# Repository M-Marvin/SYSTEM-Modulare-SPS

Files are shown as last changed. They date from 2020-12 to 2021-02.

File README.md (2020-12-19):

# SYSTEM-Modulare-SPS
Eine Modulares SPS System aus einem Raspberry Pi und ATmega328 Microcontrolern

Das Projekt ist noch nicht fertig, aber auf einem Steckbrett hat es schon funktioniert!

WISCHTIG: Datei wird auf der GitHub Webseite verbuggt angezeigt, besser runterladen und mit standart Texteditor öffnen!

-----------------------------------------------------------------------------------------------------

Die Modulare SPS besteht aus einem Raspberry Pi. der über ein Adaptermodul und
einem Flachbandkabel mit den einzelnen Modulen verbunden wird.

Die Moduel bestehen aus auf Hut-Schienen anbringbaren 3D-Gedruckten Gehäusen mit
entsprechenden Schaltungen darin.

Bisherige Module:
  - keine

In Entwiklung:
  - DO_16_R230  16 x Digitalausgang mit 230V Relay-Wechlerkontakten

Geplante Module:
  - DI_16_D24   16 x Digitaleingang 24V direkt gekoppelt (keine Relays dazwischen)
  - AI_1_D0-24  1 x Analogeingang 0V-24V direkt gekoppelt
  - AO_1_D0-24 1 x Analogausgang 0V-24V direkt gekoppelt (benötigt 24V Spannungsversorgung)

-----------------------------------------------------------------------------------------------------

Kurzbezeichnungs-Legende:

Beispiel: DO - 16 - R230

D = Digital (1 oder 0 / Ein oder Aus)
O = Output (Ausgang)

16 = Schnittstelle 16 mal vorhanden

R = Relay/Galvanisch getrennt
230 = Maximale Spannung 230V

Zusammensetzung: [Art der Schnittstelle] [Eingang/Ausgang*] _ [Anzahl der Schnittstellen] _ [Kopplungsart] [Maximal-Spannung/Spannungsbereich]
* (oder weggelassen wenn nicht klar definierbar, z.B: bei Netzwerk)

[Art der Schnittstelle]
- D Digital
- A Analog
- B Bus-System (zu Zeit noch nicht verwended, z.B. Netzwerk, D-Sub, MPI, ISP, USB, usw.)

[Eingang/Ausgang]
- I Eingang
- O Ausgang

[Kopplungsart]
- R Relay/Galvanisch getrennt
- D Direkt gekoppelt (GND der Leiterplatte/SPS und GND der Externen Anschlüsse sind identisch)

-----------------------------------------------------------------------------------------------------

Das projekt besteht aus:
- Raspberry Pi SPS Hauptprogramm (Dort wird das Programm der Steuerung und die Einstellung der Module reingeladen)
- ATmega Modul-Programme (Programme der jeweiligen Module)
- Schaltpläne/Leiterplatten entwürfe
- 3D-Druck Modelle für Gehäuse/Halterungen

Das Raspberry Pi Programm läuft mit der Bibliothek pi4j auf jedem kompatiblen Raspebrry Pi.
Die Datei wird einfach auf das Pi kopiert und über einen der folgenden Befehle gestartet:
    sudo java -jar *Pfad der Jar*               um das SPS Programm zu starten
    sudo java -jar *Pfad der Jar* -configMode   um den System-Konfigurator zu starten und die Adressen der Module fest zu legen

Die ATmega Programme werden als .hex (Textdatei mit Hexadezimal-Codes) compiliert und per SPI in den Controler geladen.

-----------------------------------------------------------------------------------------------------

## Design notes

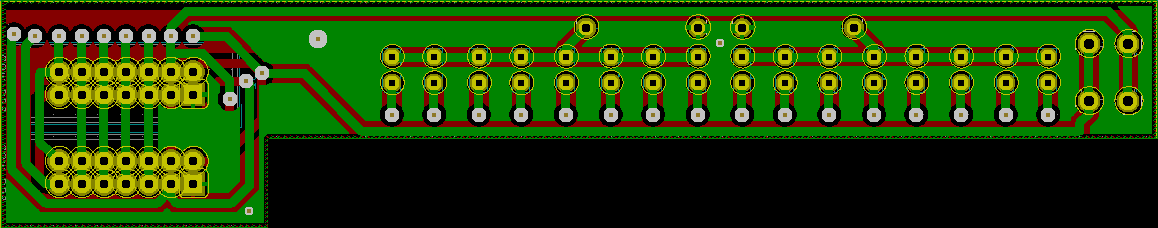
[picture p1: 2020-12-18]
Projekt-3D-Modelle/DO_16_R230/DO_16_R230 Front.PNG

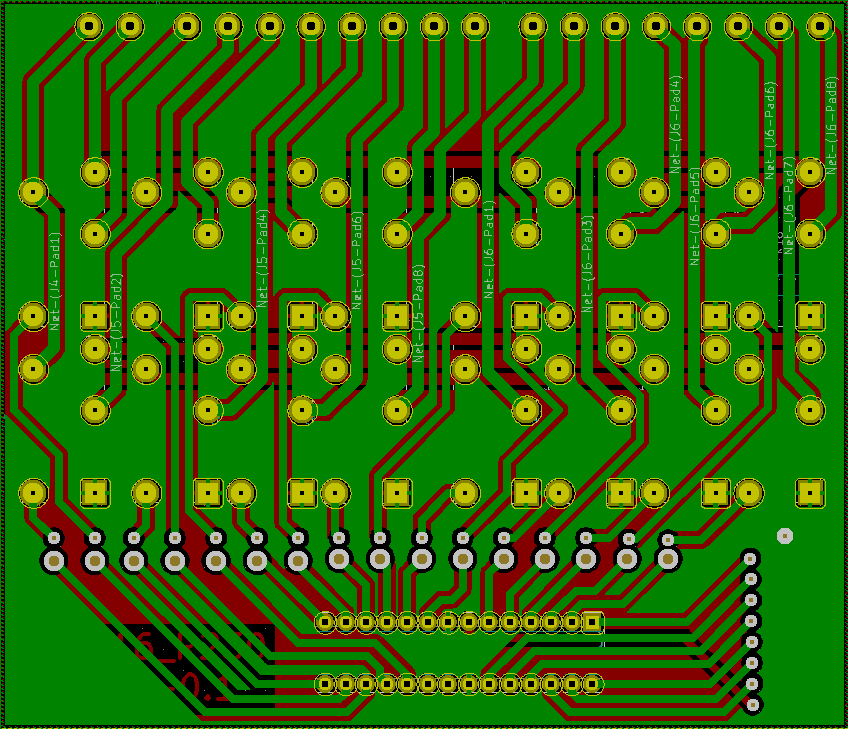
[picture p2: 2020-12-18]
Projekt-3D-Modelle/DO_16_R230/DO_16_R230 Main.PNG

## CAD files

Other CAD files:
Projekt-3D-Modelle/DO_16_R230/Gesamt.skp

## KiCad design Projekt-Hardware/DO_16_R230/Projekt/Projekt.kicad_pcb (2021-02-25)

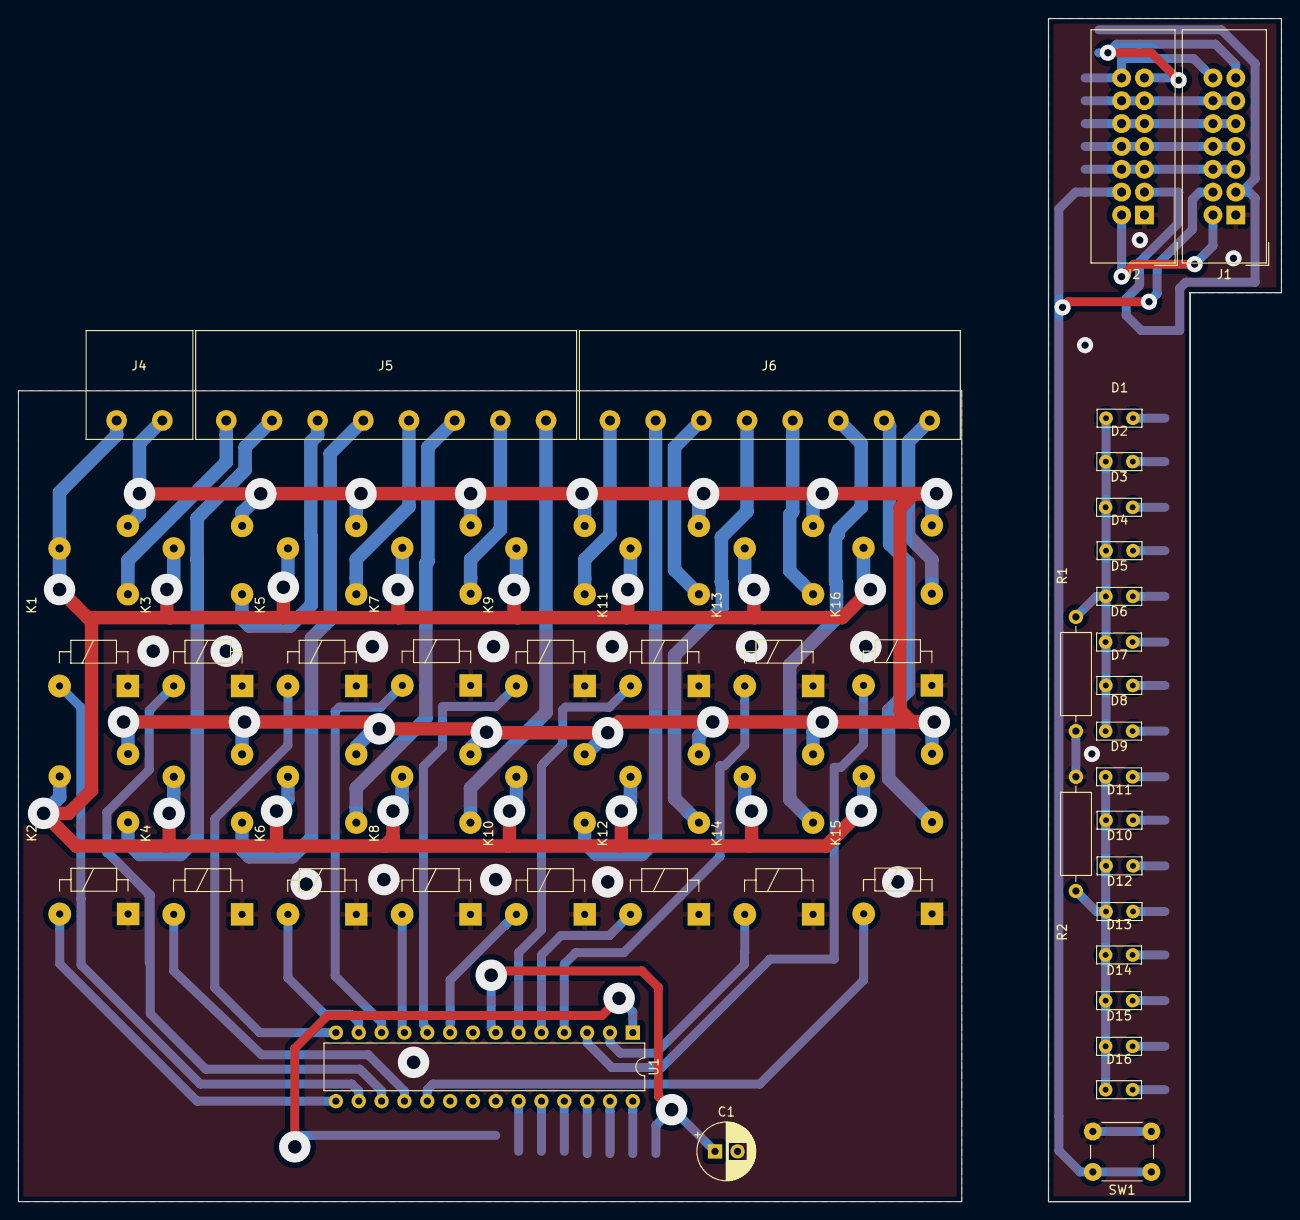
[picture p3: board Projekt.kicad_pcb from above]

Board: 2 copper layers, 140.5 x 131.6 mm, 42 parts (0 on the bottom side), 46 nets.

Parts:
C1: 10uF; CP_Radial_D6.3mm_P2.50mm
D1, D2, D3, D4, D5, D6, D7, D8, D9, D10, D11, D12, D13, D14, D15, D16: LED; LED_5x2mm
J1, J2: COM_Bus; IDC-Header_2x07_P2.54mm_Vertical
J4: Conn_01x02; RND_Steckklemme_2
J5, J6: Conn_01x08; RND_Steckklemme_8
K1, K2, K3, K4, K5, K6, K7, K8, K9, K10, K11, K12, K13, K14, K15, K16: DIPxx-1Cxx-51x; Relay_1-Form-C-20,6x10,2mm
R1, R2: 220R; R_Axial_DIN0309_L9.0mm_D3.2mm_P12.70mm_Horizontal
SW1: RESET; SW_PUSH_6mm_H8mm
U1: ATmega328P-PU; DIP-28_W7.62mm

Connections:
/+5V: C1.1, J1.2, J2.2, U1.7
/-5V: J1.3, J2.3
/CLOCK: J1.13, J2.13, U1.27
/COM_IN_1: J1.5, J1.6, J2.5, J2.6, U1.25
/COM_IN_2: J1.7, J1.8, J2.7, J2.8, U1.26
/COM_OUT_1: J1.9, J1.10, J2.9, J2.10, U1.23
/COM_OUT_2: J1.11, J1.12, J2.11, J2.12, U1.24
/ENABLE: J1.14, J2.14, U1.28
/GND: C1.2, J1.1, J2.1, K1.6, K2.6, K3.6, K4.6, K5.6, K6.6, K7.6, K8.6, K9.6, K10.6, K11.6, K12.6, K13.6, K14.6, K15.6, K16.6, R1.2, R2.2, SW1.0,82, SW1.2, U1.8, U1.22
/RESET: J1.4, J2.4, SW1.0,81, SW1.1, U1.1
unnamed: D1.1, D2.1, D3.1, D4.1, D5.1, D6.1, D7.1, D8.1, R1.1
unnamed: D1.2, K1.2, U1.16
unnamed: D2.2, K2.2, U1.15
unnamed: D3.2, K3.2, U1.17
unnamed: D4.2, K4.2, U1.18
unnamed: D5.2, K5.2, U1.14
unnamed: D6.2, K6.2, U1.13
unnamed: D7.2, K7.2, U1.12
unnamed: D8.2, K8.2, U1.11
unnamed: D9.2, K9.2, U1.10
unnamed: D9.1, D10.1, D11.1, D12.1, D13.1, D14.1, D15.1, D16.1, R2.1
unnamed: D10.2, K10.2, U1.9
unnamed: D11.2, K11.2, U1.6
unnamed: D12.2, K12.2, U1.5
unnamed: D13.2, K13.2, U1.4
unnamed: D14.2, K14.2, U1.2
unnamed: D15.2, K15.2, U1.19
unnamed: D16.2, K16.2, U1.3
unnamed: J4.1, K1.1, K2.1, K3.1, K4.1, K5.1, K6.1, K7.1, K8.1, K9.1, K10.1, K11.1, K12.1, K13.1, K14.1, K15.1, K16.1
unnamed: J4.2, K1.14, K2.14, K3.14, K4.14, K5.14, K6.14, K7.14, K8.14, K9.14, K10.14, K11.14, K12.14, K13.14, K14.14, K15.14, K16.14
unnamed: J5.1, K1.7
unnamed: J5.2, K2.7
unnamed: J5.3, K3.7
unnamed: J5.4, K4.7
unnamed: J5.5, K5.7
unnamed: J5.6, K6.7
unnamed: J5.7, K7.7
unnamed: J5.8, K8.7
unnamed: J6.1, K9.7
unnamed: J6.2, K10.7
unnamed: J6.3, K11.7
unnamed: J6.4, K12.7
unnamed: J6.5, K13.7
unnamed: J6.6, K14.7
unnamed: J6.7, K15.7
unnamed: J6.8, K16.7

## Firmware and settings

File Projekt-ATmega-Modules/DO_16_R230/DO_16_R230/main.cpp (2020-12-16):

/*
 * comInterface.c
 * Module main file
 *
 * Created: 11/16/2020 7:30:22 PM
 *  Author: Marvin
 * 
 * PIN CONFIG
 * Relays
 * PORTD 0-7 + PORTB 0-7
 * COM Serial OUT
 * PORTC 0-1
 * COM Serial IN
 * PORTC 2-3
 * Clock
 * PINC 4
 */ 

#include "system.cpp"

int main(void)
{
	
	System sys;
	sys.start();
	
}

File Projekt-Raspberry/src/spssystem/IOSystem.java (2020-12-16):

package spssystem;

import com.pi4j.io.gpio.GpioController;
import com.pi4j.io.gpio.GpioFactory;
import com.pi4j.io.gpio.GpioPinDigitalInput;
import com.pi4j.io.gpio.GpioPinDigitalOutput;
import com.pi4j.io.gpio.PinPullResistance;
import com.pi4j.io.gpio.PinState;
import com.pi4j.io.gpio.RaspiPin;

public class IOSystem {
	
	protected boolean clockPulseState;
	protected byte[] inputList;
	protected byte[] inputBytes;
	protected byte[] outputList;
	protected byte[] outputBytes;
	
	protected GpioController gpio;
	protected GpioPinDigitalOutput outputEnable;
	protected GpioPinDigitalOutput outputSync;
	protected GpioPinDigitalOutput outputCom1;
	protected GpioPinDigitalOutput outputCom2;
	protected GpioPinDigitalInput inputCom1;
	protected GpioPinDigitalInput inputCom2;
	
	public IOSystem() {
		this.inputBytes = new byte[0];
		this.inputList = new byte[0];
		this.outputBytes = new byte[0];
		this.outputList = new byte[0];
		
		try {
			gpio = GpioFactory.getInstance();
			outputEnable = gpio.provisionDigitalOutputPin(RaspiPin.GPIO_01, "enable", PinState.LOW);
			outputEnable.setShutdownOptions(true, PinState.LOW, PinPullResistance.OFF);
			outputSync = gpio.provisionDigitalOutputPin(RaspiPin.GPIO_08, "sync", PinState.LOW);
			outputSync.setShutdownOptions(true, PinState.LOW, PinPullResistance.OFF);
			outputCom1 = gpio.provisionDigitalOutputPin(RaspiPin.GPIO_09, "oCom1", PinState.LOW);
			outputCom1.setShutdownOptions(true, PinState.LOW, PinPullResistance.OFF);
			outputCom2 = gpio.provisionDigitalOutputPin(RaspiPin.GPIO_07, "oCom2", PinState.LOW);
			outputCom2.setShutdownOptions(true, PinState.LOW, PinPullResistance.OFF);
			inputCom1 = gpio.provisionDigitalInputPin(RaspiPin.GPIO_00, "iCom1");
			inputCom1.setPullResistance(PinPullResistance.PULL_DOWN);
			inputCom2 = gpio.provisionDigitalInputPin(RaspiPin.GPIO_02, "iCom2");
			inputCom2.setPullResistance(PinPullResistance.PULL_DOWN);
		} catch (UnsatisfiedLinkError e) {
			System.err.println("SPSSystem cant connect to wiringPi netive Lib!");
			System.err.println(e.getMessage());
			System.exit(-1);
		}
		
	}
	
	public void shutdown() {
		this.gpio.shutdown();
	}
	
	public void registerInputRange(byte adress, byte byteWidth, int requestTime) {
		
		inputList = ByteUtility.mergeData(inputList, new byte[] {adress, byteWidth}, ByteUtility.intToBytes(requestTime));
		inputBytes = ByteUtility.mergeData(this.inputBytes, new byte[byteWidth]);
		
	}
	
	public void registerOutputRange(byte adress, byte byteWidth, int updateTime) {
		
		outputList = ByteUtility.mergeData(outputList, new byte[] {adress, byteWidth}, ByteUtility.intToBytes(updateTime));
		outputBytes = ByteUtility.mergeData(this.outputBytes, new byte[byteWidth]);
		
	}
	
	public void setOutputByte(byte adr, int targetByte, byte ioByte) {

		int ioByteOffset = 0;
		for (int modCnt = 0; modCnt < outputList.length; modCnt += 6) {
			
			byte adress = outputList[modCnt + 0];
			byte byteWidth = outputList[modCnt + 1];
			
			if (adress == adr && targetByte < byteWidth) {
				
				this.outputBytes[ioByteOffset + targetByte] = ioByte;
				
			}
			
			ioByteOffset += byteWidth;
			
		}
				
	}
	
	public byte getOutputByte(byte adr, int targetByte) {
		
		int ioByteOffset = 0;
		for (int modCnt = 0; modCnt < outputList.length; modCnt += 6) {
			
			byte adress = outputList[modCnt + 0];
			byte byteWidth = outputList[modCnt + 1];
			
			if (adress == adr && targetByte < byteWidth) {
				
				return this.outputBytes[ioByteOffset + targetByte];
				
			}
			
			ioByteOffset += byteWidth;
			
		}
		
		return 0;
		
	}

	public void setInputByte(byte adr, int targetByte, byte ioByte) {

		int ioByteOffset = 0;
		for (int modCnt = 0; modCnt < inputList.length; modCnt += 6) {
			
			byte adress = inputList[modCnt + 0];
			byte byteWidth = inputList[modCnt + 1];
			
			if (adress == adr && targetByte < byteWidth) {
				
				this.inputBytes[ioByteOffset + targetByte] = ioByte;
				
			}
			
			ioByteOffset += byteWidth;
			
		}
				
	}
	
	public byte getInputByte(byte adr, int targetByte) {
		
		int ioByteOffset = 0;
		for (int modCnt = 0; modCnt < inputList.length; modCnt += 6) {
			
			byte adress = inputList[modCnt + 0];
			byte byteWidth = inputList[modCnt + 1];
			
			if (adress == adr && targetByte < byteWidth) {
				
				return this.inputBytes[ioByteOffset + targetByte];
				
			}
			
			ioByteOffset += byteWidth;
			
		}
		
		return 0;
		
	}
	
	protected void waitTick() {
		try {
			Thread.sleep(0, 100);
		} catch (InterruptedException e) {
			// TODO Auto-generated catch block
			e.printStackTrace();
		}
	}
	
	public void readInputs() {

		setLow();
		outputEnable.high();
		
		long sysClock = SPSSystem.getSystem().getSystemClock();
		int ioByteOffset = 0;
		
		for (int modCnt = 0; modCnt < inputList.length; modCnt += 6) {
			
			byte adress = inputList[modCnt + 0];
			byte byteWidth = inputList[modCnt + 1];
			int requestTime = ByteUtility.bytesToInt(ByteUtility.copyArr(inputList, modCnt + 2, modCnt + 5));
			
			if (sysClock % requestTime == 0) {
				
				waitTick();
				
				byte[] data = readModul(adress);
				
				if (data.length >= byteWidth) {
					
					byte[] data2 = ByteUtility.copyArr(data, 0, byteWidth);
					ByteUtility.replaceBytes(this.inputBytes, ioByteOffset, data2);
					
				}
				
			}
			
			ioByteOffset += byteWidth;
			
		}

		setLow();
		outputEnable.low();
		
	}
	
	public void writeOutputs() {
		
		setLow();
		outputEnable.high();
		
		long sysClock = SPSSystem.getSystem().getSystemClock();
		int ioByteOffset = 0;
		
		for (int modCnt = 0; modCnt < outputList.length; modCnt += 6) {
			
			byte adress = outputList[modCnt + 0];
			byte byteWidth = outputList[modCnt + 1];
			int requestTime = ByteUtility.bytesToInt(ByteUtility.copyArr(outputList, modCnt + 2, modCnt + 5));
			
			if (sysClock % requestTime == 0) {

				waitTick();
				
				byte[] data = ByteUtility.copyArr(this.outputBytes, ioByteOffset, ioByteOffset + byteWidth - 1);
				writeModul(adress, data);
				
			}
			
			ioByteOffset += byteWidth;
			
		}

		setLow();
		outputEnable.low();
		
	}
	
	public byte[] writeAdressConfig(byte adress, byte masterAdress) {
		
		setLow();
		outputEnable.high();
		
		byte[] data = new byte[] {adress};
		writeModul(masterAdress, data);
		byte[] response = readBytes();
		
		setLow();
		outputEnable.low();
		
		return response;
		
	}
	
	protected void setLow() {
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

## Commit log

2020-12-07 Hochladen des Aktuellen Projekt-Stands
    Raspberry:
    - Java-Software zum betrieb der Steuerung
    - Netzwerk fähig
    - GPIO/Module (Ein/Ausgänge) noch nicht implementiert
    ATmega:
    - Software für DO_16_R230 (16x230V Relay-Ausgänge) Modul
    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
    [Projekt.kicad_pcb, Projekt.sch]
2020-12-16 Modul-Kommunikation fertig
    Protokoll zur Kommunikation zwischen
    ATmega und Raspberry Pi fertig gestellt.
    (Änderungen kommen eventuell noch)
2020-12-16 EEPROM Speicher für Modul Adresse
    Die Adresse des Moduls DO_16_R230 wird
    jetzt bei Ein/Aus schalten im EEPROM des ATmega328 gespeichert.
2020-12-17 Erster (meschanischer) Entwurf für DO_16_R230 Modul
    Erster Entwurf für meschanische Bauteile des
    DO_16_R230 Moduls:
    - Entwurf für Leiterplatten
    Fehlende Entwürfe:
    - Gehäuse
    - Halterungen
    [Projekt.kicad_pcb, Projekt.sch]
2020-12-17 BugFix PortState Abfrage DO_16_R230 Modul
    PORT Angaben bei der Abfrage der Ausgangszustände korigiert.
    Unnötiges "Testprojekt" gelöcht (GccApplication1).
    [system.cpp]
2020-12-18 Gehäuse für DO_16_R230 begonnen
    Angefangen Gehäuse für DO_16_R230
    angefangen zu entwerfen.
    [Gesamt.skp, Projekt.kicad_pcb, Projekt.sch]
2020-12-19 BugFix bei 3D Modells
    Fehler in den 3D Modellen behoben.
    Sie können jetzt gedruckt werden.
    [Gesamt.skp]
2020-12-19 Korrektur im Schaltplan
    RESET Taster auf von +5V auf GND verschoben.
    [Projekt.kicad_pcb, Projekt.sch]
2020-12-26 Anpassungen Gehäuse + CNC Experimente
    Anpassungen des Gehäuses an die Leiteplatte
    Angefangen mit Tests für das herstellen der Leiterplatte mit einer CNC Fräse
    [Gesamt.skp, Projekt.kicad_pcb, Projekt.sch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]
2021-02-25 Hardware CNC Codes erstellt
    Fertigungsdateien für eine CNC Version der
    Leiterplatten erstellt.
    [Projekt.kicad_pcb, Projekt.sch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]
